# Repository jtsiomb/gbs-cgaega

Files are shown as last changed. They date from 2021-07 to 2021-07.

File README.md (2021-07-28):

GBS-8200 CGA/EGA input board
============================



The GBS-8200 video upscaler is advertised as being able to convert CGA/EGA video
to VGA, but it can't handle either without further modification. The missing
pieces for being able to feed CGA and EGA video to the GBS board are the
following:

  - The GBS board accepts analog RGB video signals from 0V to 1V, while CGA and
    EGA video signals are digital with TTL logic levels.
  - The GBS board can only use combined H+V sync, while CGA and EGA have
    separate horizontal and vertical sync signals.
  - EGA modes use a 21KHz horizontal scan rate, which the GBS board does not
    accept.

This project only tackles the first two items on the list, which are sufficient
for successfully converting CGA to VGA with the GBS-8200. If you wish to make
the GBS-8200 accept EGA frequencies, you will need something like this:
https://github.com/ramapcsx2/gbs-control in conjunction with this input board.

License
-------
Copyright (C) 2021 John Tsiombikas <nuclear@member.fsf.org>

The CGA/EGA input board is a free hardware design. Feel free to use, modify,
and/or redistribute it under the terms of the GNU General Public License v3, or
at your option any later version published by the Free Software Foundation. See
LICENSE for details.

Theory of operation
-------------------
Schematic: http://nuclear.mutantstargoat.com/hw/gbs-cgaega/gbs-cgaega-schem.pdf

The CGA/EGA input board is a small daughterboard, which plugs directly over the
8-pin video input connector of the GBS-8200, and is powered by the GBS board
through the 2-pin power connector at the top-right of the board.

The CGA/EGA input board is comprised of a cheap programmable logic chip
(GAL16V8), and a simple resistor network for digital to analog conversion.

The GAL chip is programmed with the logic equations in `cgaega.pld` to:

  - Combine the H and V sync signals to combined H+V sync.
  - Convert the CGA (RGB + intensity) TTL signals, to EGA-compatible (RrGgBb)
    TTL signals.
  - Detect the CGA dark yellow, and correct it to brown.

The last two items are only enabled when the CGA/EGA switch is set to CGA input.

Bill of Materials
-----------------

  - 1x GAL16V8 programmable logic chip.
  - 1x IC socket for the GAL (10pin DIP).
  - 1x Female pin header connector 1x8 pins, 2.54mm pitch.
  - 1x JST 2.54mm pitch male pin header (optional).
  - 3x 470 ohm resistors SMD 0805.
  - 3x 680 ohm resistors SMD 0805.
  - 1x 4.7k ohm resistor SMD 0805.
  - 1x 0.1uF capacitor SMD 0805.
  - 2x through hole 3-pin SPDT PCB-mounted mini switches 2.54mm pitch.
    Alternatively 3-pin single row pin headers can be used with jumpers.
  - 1x D-SUB 9-pin female connector, PCB-mounted.

You will also need an appropriate D-SUB 9-pin cable (male to male)
to connect the CGA/EGA video card to the input board. A straight through (not
null-modem) serial cable can be used, but make sure it's fully wired; some
serial cables carry only the Rx/Tx signals and ground, and are not suitable.

For the power lead, you can solder the 2-pin power cable which comes with the
GBS-8200 board directly to the input board and plug it into the GBS power
connector. Alternatively you can install a JST 2-pin connector on the input
board, and make an appropriate cable with JST female connectors on both ends.

Build instructions
------------------
To build a CGA/EGA input board:

  - zip the contents of the `gerber` directory and send it to a PCB fabrication
    service of your choice (popular choices are jlcpcb and pcbway).
  - Acquire the necessary components (see Bill of Materials section).
  - Assemble the board, and program the GAL chip with the included pre-compiled
    `cgaega.jed` file.

A cheap EEPROM programmer like the TL866 can be used to program the GAL.

If you wish to build the JED file from the `cgaega.pld` source, you'll need
GALasm (https://github.com/daveho/GALasm). Unfortunately GALasm is not free
software; if you can suggest a free software alternative, please let me know!
When you have everything set up, simply type `make`.

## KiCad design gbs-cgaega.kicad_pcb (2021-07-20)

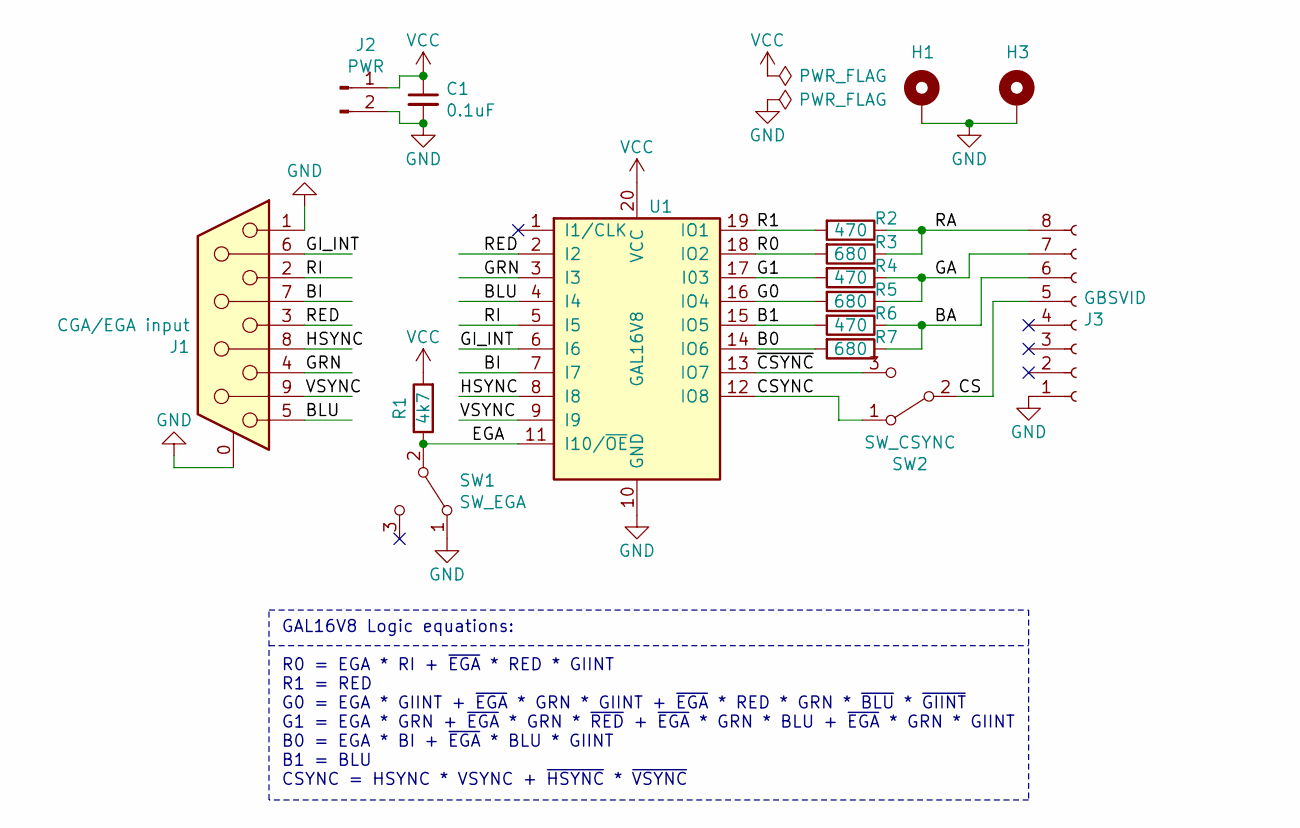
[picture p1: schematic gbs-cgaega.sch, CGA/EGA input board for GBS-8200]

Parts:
C1: 0.1uF; C_0805_2012Metric_Pad1.15x1.40mm_HandSolder
H1, H3: mhole; MountingHole_3.2mm_M3_ISO7380_Pad
J1: CGA/EGA input; DSUB-9_Female_Horizontal_P2.77x2.84mm_EdgePinOffset7.70mm_H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
J2: PWR; JST_EH_B2B-EH-A_1x02_P2.50mm_Vertical
J3: GBSVID; JST_EH_B8B-EH-A_1x08_P2.50mm_Vertical
R1: 4k7; R_0805_2012Metric_Pad1.15x1.40mm_HandSolder
R2, R4, R6: 470; R_0805_2012Metric_Pad1.15x1.40mm_HandSolder
R3, R5, R7: 680; R_0805_2012Metric_Pad1.15x1.40mm_HandSolder
SW1: SW_EGA; PinHeader_1x03_P2.54mm_Vertical
SW2: SW_CSYNC; PinHeader_1x03_P2.54mm_Vertical
U1: GAL16V8; DIP-20_W7.62mm_Socket_LongPads

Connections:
/B0: R7.2, U1.14 (IO6)
/B1: R6.2, U1.15 (IO5)
/BA: J3.6, R6.1, R7.1
/BI: J1.7, U1.7 (I7)
/BLU: J1.5, U1.4 (I4)
/CS: J3.5, SW2.2 (B)
/CSYNC: SW2.1 (A), U1.12 (IO8)
/EGA: R1.1, SW1.2 (B), U1.11 (I10/~OE~)
/G0: R5.2, U1.16 (IO4)
/G1: R4.2, U1.17 (I03)
/GA: J3.7, R4.1, R5.1
/GI_INT: J1.6, U1.6 (I6)
/GRN: J1.4, U1.3 (I3)
/HSYNC: J1.8, U1.8 (I8)
/R0: R3.2, U1.18 (IO2)
/R1: R2.2, U1.19 (IO1)
/RA: J3.8, R2.1, R3.1
/RED: J1.3, U1.2 (I2)
/RI: J1.2, U1.5 (I5)
/VSYNC: J1.9, U1.9 (I9)
/~CSYNC: SW2.3 (C), U1.13 (IO7)
GND: C1.2, H1.1, H3.1, J1.0 (PAD), J1.1, J2.2, J3.1, SW1.1 (A), U1.10 (GND)
VCC: C1.1, J2.1, R1.2, U1.20 (VCC)

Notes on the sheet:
GAL16V8 Logic equations: R0 = EGA * RI + ~EGA~ * RED * GIINT R1 = RED G0 = EGA * GIINT + ~EGA~ * GRN * GIINT + ~EGA~ * RED * GRN * ~BLU~ * ~GIINT~ G1 = EGA * GRN + ~EGA~ * GRN * ~RED~ + ~EGA~ * GRN * BLU + ~EGA~ * GRN * GIINT B0 = EGA * BI + ~EGA~ * BLU * GIINT B1 = BLU CSYNC = HSYNC * VSYNC + ~HSY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

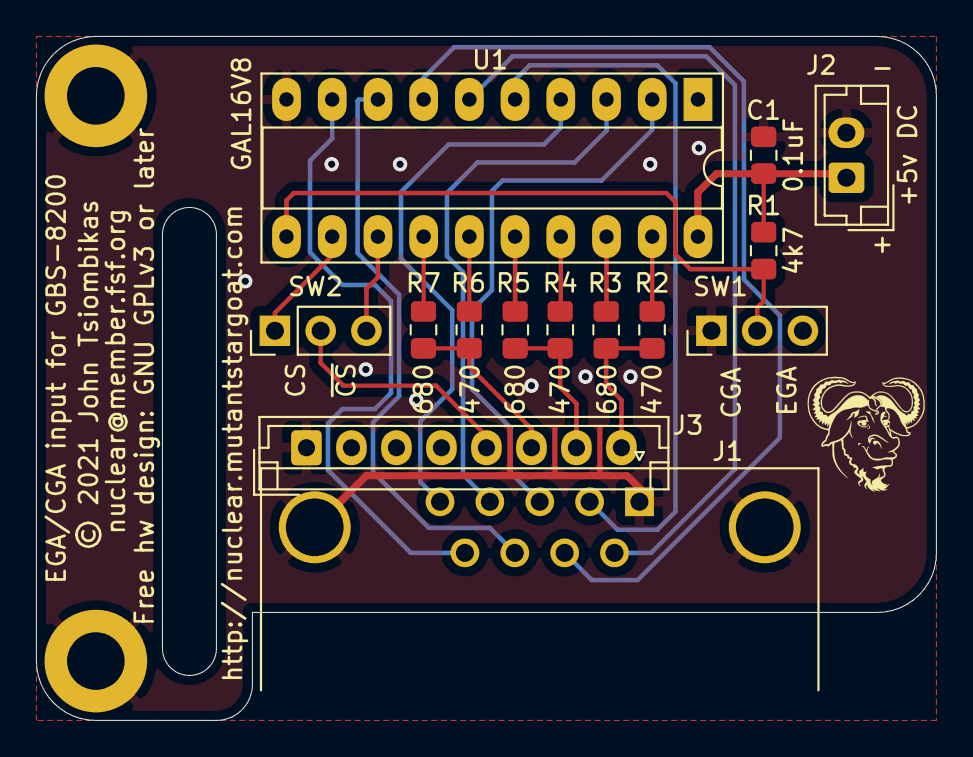
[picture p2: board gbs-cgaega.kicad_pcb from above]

Board: 2 copper layers, 50.0 x 38.0 mm, 16 parts (0 on the bottom side), 23 nets.

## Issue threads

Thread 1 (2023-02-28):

Not Working With GBS Control

c64manguy, 2023-02-28:
Hey All.
Has anyone gotten this working with a GBS-Control modded gbs8200 or 8220? I had 10 boards built and soldered on the components. I programmed the gal with cgaega.jed and when I turn the computer on (IBM XT 286) with an EGA card I just get a bunch of white scrambled up nonsense jumping around the top of the screen...

jtsiomb, 2023-02-28:
I haven't tried gbs-control yet. I would assume it's orthogonal, that gbs-control would just enable accepting 21khz sync signals. But maybe it also changes the sync required to separate H/V sync instead of combined H+V ? Or is there an option for this in gbs-control? If you figure it out let us know.

c64manguy, 2023-02-28:
Have you had it working on a normal GBS8200 or 8220? With out the GBS-Control mods?

jtsiomb, 2023-02-28:
Yes, mine is a GBS 8200. I don't know the differences between that and the 8220.

c64manguy, 2023-02-28:
Im going to try it with a regular GBS-8200 and see what happens. My EGA card could be bad. With the GBS-Control I have been able to get a dim output as long as the EGA card isnt set to High Res Mode. Can you tell me what the CS and NOT-CS are for? And what they should be set to?

c64manguy, 2023-02-28:
I hooked it up with a standard GBS8200 board and it worked with text but when I tried to load Windows 3.1 it lost sync. Not sure if my EGA card is messed up or not. Can you load Windows 3.1 on yours or color modes in general or are you using yours for something else?

jtsiomb, 2023-02-28:
Not easily. I've got the CGA card on an 8088 XT clone without a hard disk at the moment. I could try some CGA game to test, but it will take a while, as I've got all that hardware stashed at the moment.

c64manguy, 2023-03-01:
Oh, I was asking you to try it yourself. Just wondering what you used yours for. You've done plenty just making the board for everyone to use. Thank you.
I ordered the parts to make a sync stripper. I'll see if that helps.

banman11, 2023-06-22:
Hi very interesting discussion. I think the deffeeernce between the GBS 8200 and GBS 8220 boards in the inclusion of a second VGA output adapter.

theos10, 2024-09-05:
Hi my cga computer not work with gbs-8200 moded or not, and samsung 151mp display

jtsiomb, 2024-09-05:
Since this original discussion I have modded my GBS-8200 with gbs-control, and it works perfectly fine with my CGA/EGA input board.

EGA 21khz modes however are very hard to get to sync right, but CGA modes work and are much crisper than with the unmodified GBS board.

Here's a screenshot of my termtris game running on EGA 21khz. It mostly syncs after a fair bit of tweaking, but it looses it once in a while, and always distorts the top of the screen:
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

banman11, 2024-09-05:
Hi jtsiomb,

Looks interesting, good job.

I haven't had time to revisit this discussion.

However, some time back I purchased this cheap GBS 8200 (I assume it is)....

AU$33.79 | Arcade Game RGB/CGA/EGA/YUV To VGA HD Video Converter Board HD9800/GBS8200 Hot Green Board
https://a.aliexpress.com/_ms7itXw

Now I had a great deal of issues with screen treating/ sync? with my c128 setup.
Quite by accident I discovered that by momentarily shorting out a jumper on the GBS board the issue disappeared entirely.

I am no expert on this. I think shorting out the jumper disables the on screen menu processor which is causing the tearing/ sync issues.

NOTE: shorting this jumper out disables the on screen menu. Starting the GBS board resets it back to it's factory state.

On my GBS board it's the only 2 pin jumper there, easy enough to tell..

Maybe this is of interest to people having screen issues.

banman11, 2024-09-05:
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

banman11, 2024-09-05:
Looks like this different GBS variant has it one as well.
![Uploading Screenshot_2024-09-06-06-51-12-001_cn.wps.moffice_eng.png…]()

Verault, 2025-04-15:
Does anyone have one of these boards to sell or know if someone is selling them. I would really like to build one but dont need to order a bunch of boards just to make one.

jtsiomb, 2025-04-16:
> Does anyone have one of these boards to sell or know if someone is selling them. I would really like to build one but dont need to order a bunch of boards just to make one.

The minimum order at JLCPCB is 5 boards, and it costs like $2. Build one and throw the other 4 away.

Verault, 2025-04-16:
My OCD would never let me do that.

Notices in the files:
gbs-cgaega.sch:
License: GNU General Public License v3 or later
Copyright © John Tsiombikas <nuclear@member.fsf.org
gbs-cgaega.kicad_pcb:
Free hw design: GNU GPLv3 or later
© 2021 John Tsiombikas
